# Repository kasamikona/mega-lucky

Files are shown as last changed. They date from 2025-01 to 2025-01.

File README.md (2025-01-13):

# Mega-Lucky
Ultimate IO mod for the Lucky Group electronic guitar toy (らっき組 ギター) RK-001, made by People Co., Ltd.  

The guitar toy in question has no external connectors. None at all, not even a headphone jack.
This project adds a 3.5mm line-out, a 6VDC barrel jack power input,
and MIDI in/out through additional 3.5mm TRS jacks.  

## Line out
The line-level audio output is amplified from the DAC output directly.
The DAC is stereo but the built-in volume pot is only mono, so I have chosen to bypass the pot for line-out.
In the future I may look into ways of including the pot without significant physical mods.
There are option jumpers to filter out the strong bass designed for the internal speaker.  

## Power
The power input intercepts the battery connector to allow external 6VDC as an alternative.
The safe range is actually 4.5 to 9 volts, but the built-in regulator will run hotter at higher voltages.
There is no overvoltage protection, but polarity protection and minimal filtering is included.  

## MIDI
The MIDI connections take advantage of some unlabeled test points on the guitar's PCB.
The guitar is based around a Yamaha XU947C0 LSI chip, which integrates a CPU and MIDI synth.
I found that its MIDI input and output pins (same pins as on a DB51XG) are fully functional.
Input may be used as a MIDI synth module combined with line-out, while output implements a basic MIDI guitar controller.
The Mega-Lucky board provides these MIDI in/out connections via type-A\* TRS connectors.  

## Installation
A proper visual installation guide will be made once the full functionality of the mod is verified.  

For now some rough steps:
- Desolder speaker wires, take the main board out.
- Remove two mixing resistors R10,R45 from the main board.
- Add two wires and optional shield to the DAC (IC3) output pins (L closest to pot).
- If reusing original battery connector, desolder it and install on mod board, otherwise use new connector.
- Use the 3D-printed drill guide to mark and drill holes (6.5-7mm for TRS, 8-9mm for DC).
- Solder the audio wires to the marked points on the mod board.
- Carefully wiggle the main board and mod connectors into place, mind the ribbon cables.
- Put M3 washers (0.5mm thick) between the boards at the screw holes and screw everything back in.
- Wire the MIDI pads to the relevant test points\*\*.
- Solder remaining 6 pads to the adjacent pads/pins.
- Resolder speaker wires or add some kind of connector.
- Solder the `HI-BASS` option jumper if desired. DO NOT set the `LOUD` jumpers on v1.0 boards.
- Solder MIDI type jumpers\* for your adapters.
- Extend the battery cable if necessary to reach the new location. Don't plug into old location.\*\*\*

\* MIDI TRS type:
Recommended type A (MIDI standard, KORG, Akai, Make Noise etc).
Alternative type B (Arturia, Novation etc).
You may need extra wire clippings to bridge the jumpers for type B on v1.0 boards.  

\*\* MIDI test points (will add photos later):
Below the big `DY798` text, the second test point down is MIDI out (to `M.TX`).
Further down are 2 more points, furthest to the right is MIDI in (to `M.RX`).  

\*\*\* Battery connector safety:
The original battery connector pads are not disconnected when external DC is used.
Using these may cause extensive damage if external DC is connected with batteries in place.
You must plug the battery cable into the new location on the mod board instead.  

## PCB assembly notes
- Clean out castellated pads with tweezers if produced the cheap way (i.e. not paying for special routing).
- Shave the top-front straight edge of the TRS connectors if new to ensure a proper fit.
- You may wish to leave some connector pins unsoldered to allow realigning during installation.
- Don't populate Q1-Q3, R25-R28, these are experimental alternative MIDI out driver.
- DO NOT set the `LOUD` jumpers on v1.0 boards, this is broken. Leave R19-R22 & C13 unpopulated.

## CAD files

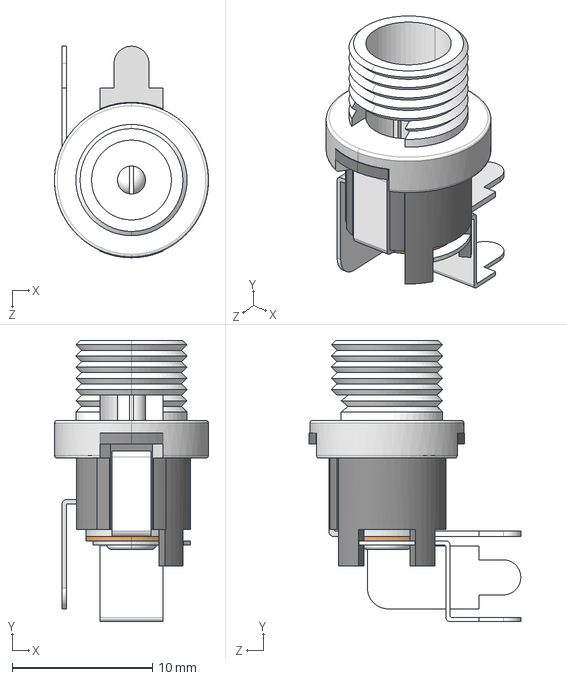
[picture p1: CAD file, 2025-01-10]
ConnectorMod/PJ-066A.step
11.0 x 20.1 x 15.1 mm

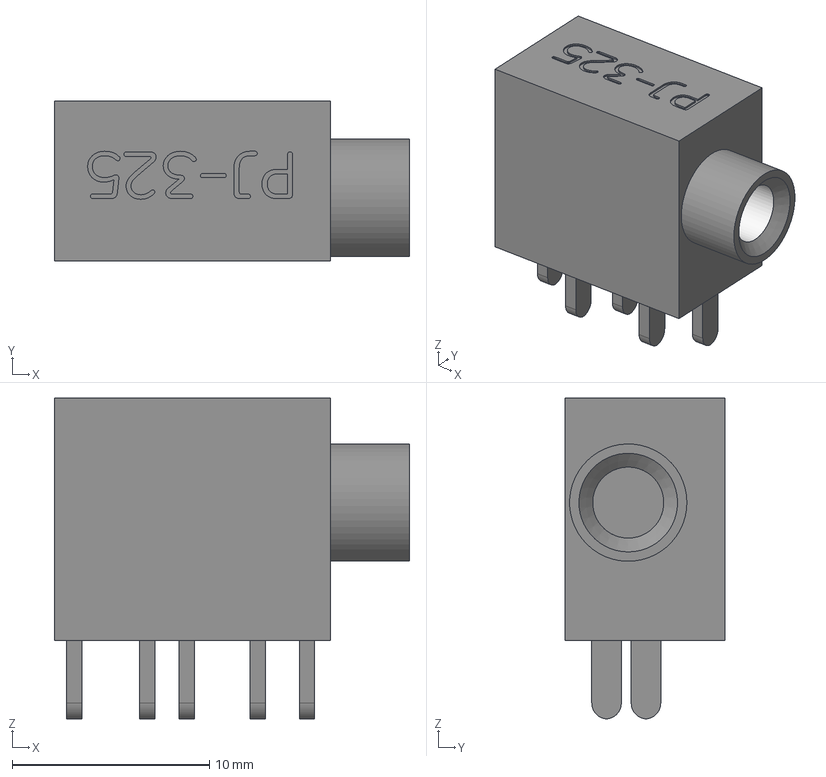
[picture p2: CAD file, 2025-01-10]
ConnectorMod/PJ-325.stp
18.0 x 8.10 x 16.3 mm

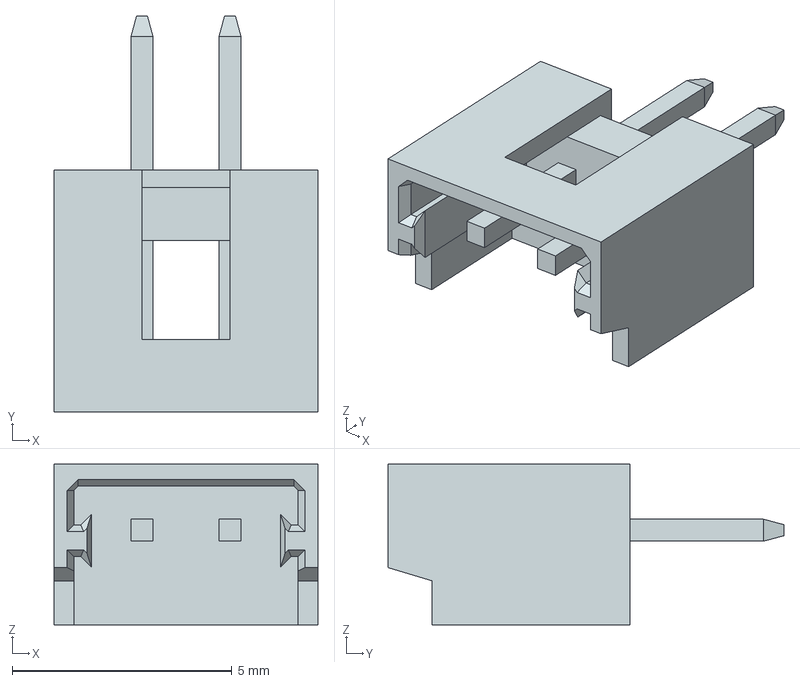
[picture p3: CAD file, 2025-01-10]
ConnectorMod/53253-0270.stp
6.00 x 9.00 x 3.65 mm

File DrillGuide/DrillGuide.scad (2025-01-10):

c1 = [-37,36.5];
c2 = [-16,149];
r1 = 60;
r2 = 62.5;
r3 = 125;

dirtyPreview=false;
renderShell=false;

boardoffset=4-0.5;
holeexp=0.;
holes = [
    [[21,21.0,6.5],15,8.0+holeexp],
    [[23,36.5,7.0], 0,6.5+holeexp],
    [[22,49.5,7.0], 0,6.5+holeexp],
    [[22,62.5,7.0], 0,6.5+holeexp],
];
shellheight=19;
shellTolerance=0.15;
pilotHole=true;

epsilon = 0.001;
cdetail = $preview?4:1;

module prerender(convexity=undef) {
    if(!dirtyPreview) {
        render(convexity) children();
    } else {
        children();
    }
}

function vlen(v) = sqrt(v.x*v.x+v.y*v.y);
function distAlongV(v,d) = v*d/vlen(v);
function cfn(r) = max(8,ceil(2*PI*r/cdetail));

function intersectTwoCircles(c1,r1,c2,r2) =
    let(x1=c1.x,y1=c1.y,x2=c2.x,y2=c2.y,
    centerdx = x1-x2, centerdy = y1-y2,
    R = sqrt(centerdx*centerdx + centerdy*centerdy),
    ttol=1e-4)
    (abs(r1-r2)<=R+ttol && r1+r2>=R-ttol) ? let(
        a = (r1*r1-r2*r2) / (2*R*R),
        r2r2 = (r1*r1-r2*r2),
        c = sqrt(max(0,2*(r1*r1+r2*r2)/(R*R)
            - (r2r2*r2r2)/(R*R*R*R) - 1)),
        fx = (x1+x2)/2 + a*(x2-x1),
        gx = c*(y2-y1)/2,
        ix1 = fx+gx,
        ix2 = fx-gx,
        fy = (y1+y2)/2 + a*(y2-y1),
        gy = c*(x1-x2)/2,
        iy1 = fy+gy,
        iy2 = fy-gy
    ) [[ix1, iy1], [ix2, iy2]] : [];

function intersectLineCircle(p1,p2,c,r) =
    let(cx=c.x,cy=c.y,p1c=p1-c,p2c=p2-c,
    x1=p1c.x,y1=p1c.y,x2=p2c.x,y2=p2c.y,
    dx=x2-x1,dy=y2-y1,dr=sqrt(dx*dx+dy*dy),
    D=x1*y2-x2*y1,
    k=r*r*dr*dr-D*D)
    (k>=0) ? let(
        dr2=dr*dr,
        kd=sqrt(k)/dr2,
        fx=D*dy/dr2+cx,
        gx=(dy<0?-1:1)*dx*kd,
        ix1=fx+gx,
        ix2=fx-gx,
        fy=(-1)*D*dx/dr2+cy,
        gy=abs(dy)*kd,
        iy1=fy+gy,
        iy2=fy-gy
    ) [[ix1, iy1], [ix2, iy2]] : [];

module outerCircles(h,off,sl) union() {
    r1a = r1-off;
    r2a = r2-off;
    r1b = r1a-h*sl;
    r2b = r2a-h*sl;
    translate(c1)
        cylinder(h=h,r1=r1b,r2=r1a,$fn=cfn(r1));
    //translate(c2)
    //    cylinder(h=h,r1=r2b,r2=r2a,$fn=cfn(r2));
}

c3 = intersectTwoCircles(c1,r1+r3,c2,r2+r3)[0];
module innerCircleFill(h,off,sl) {
    r3a = r3+off;
    r3b = r3a+h*sl;
    rs=max(0,-h*sl);
    ip1 = c1+distAlongV(c3-c1,r1-off+rs);
    ip2 = c2+distAlongV(c3-c2,r2-off+rs);
    
    prerender(convexity=10)
    difference() {
        linear_extrude(h)
        hull() {
            translate(c1) circle(r=epsilon);
            translate(ip1) circle(r=epsilon);
            translate(ip2) circle(r=epsilon);
            translate(c2) circle(r=epsilon);
        }
        translate([0,0,-epsilon])
        translate(c3) cylinder(h=h+2*epsilon,
            r1=r3b,r2=r3a,$fn=cfn(r3));
    }
}

module inclusionShape(h,xoff) {
    translate([0,0,-epsilon])
    linear_extrude(h+2*epsilon)
    polygon([
        [-xoff,xoff],[50,-50],[50,75],
        [-xoff,75+(50+xoff)/5]
    ]);
}

module endRoundProfile() {
    tol=shellTolerance;
    ww=3;
    xo=(4.5+ww)/2+tol;
    yo=0;
    ch1=shellheight+1-4.5;
    ch2=shellheight+1-2.0;
    union() {
        translate([-xo,yo,4.5])
            cylinder(h=ch1,d=ww,$fn=cfn(ww)*2);
        translate([xo,yo,2.0])
            cylinder(h=ch2,d=ww,$fn=cfn(ww)*2);
        translate([0,0,shellheight+1+3])
        rotate([90,0,0])
        linear_extrude(ww,center=true)
        polygon([
            [-xo-ww/2-1.5,0],
            [-xo-ww/2,-3],
            [xo+ww/2,-3],
            [xo+ww/2+1.5  ,0]
        ]);
    }
}

module endRounds() {
    ep1 = intersectLineCircle([0,0],[50,-50],
        c1,r1-2.25)[1];
    ea1 = 45;
    ep2 = intersectLineCircle([0,85],[50,75],
        c3,r3+2.25)[0];
    ea2 = atan(1/5);
    ch = shellheight+1;
    translate(ep1) rotate([0,0,-ea1])
        endRoundProfile();
    translate(ep2) rotate([0,0,-ea2])
        endRoundProfile();
}

module previewShell() {
    h=shellheight;
    color("#8AF")
    //prerender()
    difference() {
        intersection() {
            difference() {
                union() {
                    outerCircles(h,0,0.07);
                    innerCircleFill(h,0,0.07);
                }
                translate([0,0,3])
                union() {
                    outerCircles(h,4.5,0);
                    innerCircleFill(h,4.5,0);
                }
            }
            inclusionShape(h,0);
        }
        for(hole = holes) {
            hpos = hole[0];
            hangl = hole[1];
            hdiam = hole[2];
            translate([hpos[0],hpos[1],
                h-hpos[2]-boardoffset])
            rotate([0,90,-hangl])
            cylinder(h=10,d=hdiam,
                center=true,$fn=cfn(hdiam/2)*2);
        }
    }
}
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

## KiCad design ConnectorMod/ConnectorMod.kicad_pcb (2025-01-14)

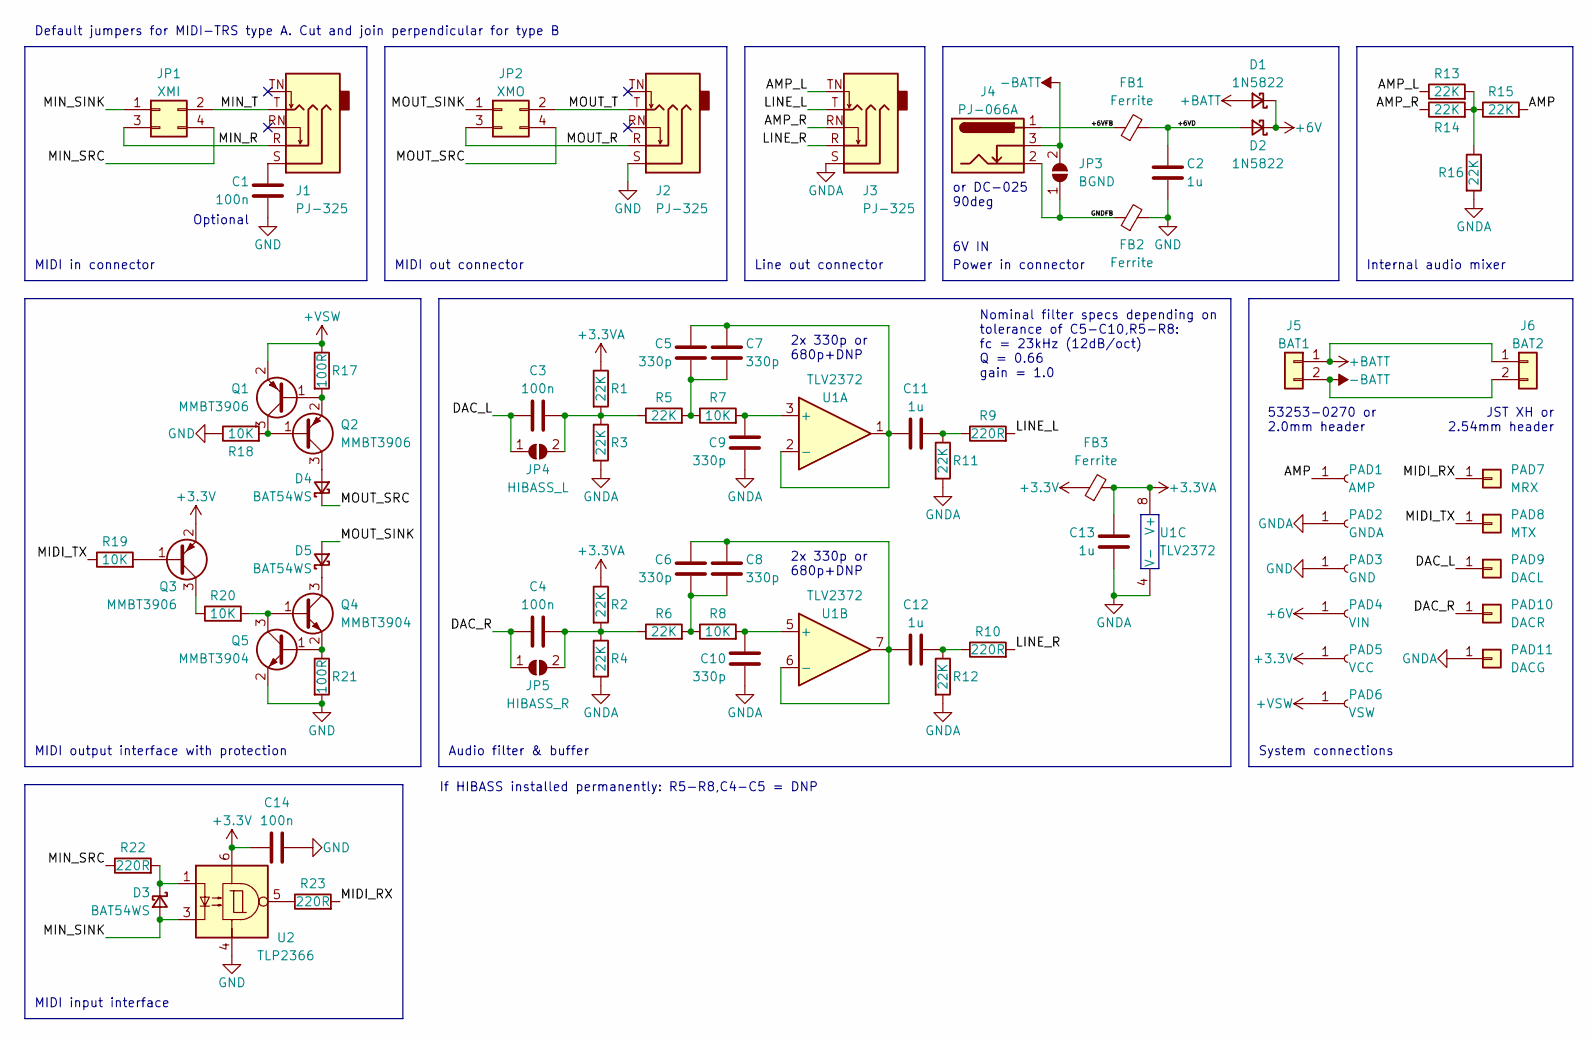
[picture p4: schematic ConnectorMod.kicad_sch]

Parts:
C1, C14: 100n; C_0603_1608Metric
C2, C11, C12, C13: 1u; C_0805_2012Metric
C3, C4: 100n; C_0805_2012Metric
C5, C6, C7, C8, C9, C10: 330p; C_0805_2012Metric
D1, D2: 1N5822; D_SMA
D3, D4, D5: BAT54WS; D_SOD-323
FB1, FB2, FB3: Ferrite; L_1206_3216Metric_Pad1.22x1.90mm_HandSolder
J1, J2, J3: PJ-325; PJ-325_Castellated-Edge
J4: PJ-066A
J5: BAT1; Molex_Micro-Latch_53253-0270_1x02_P2.00mm_Vertical
J6: BAT2; JST_XH_B2B-XH-A_1x02_P2.50mm_Vertical
JP1: XMI; SolderJumper_Cross
JP2: XMO; SolderJumper_Cross
JP3: BGND; SolderJumper_Custom
JP4: HIBASS_L; SolderJumper_Custom
JP5: HIBASS_R; SolderJumper_Custom
PAD1: AMP; Castellated-Pad_Custom
PAD2: GNDA; Castellated-Pad_Custom
PAD3: GND; Castellated-Pad_Custom
PAD4: VIN; Castellated-Pad_Custom
PAD5: VCC; Castellated-Pad_Custom
PAD6: VSW; Castellated-Pad_Custom
PAD7: MRX; TestPoint_Pad_D2.0mm
PAD8: MTX; TestPoint_Pad_D2.0mm
PAD9: DACL; TestPoint_THTPad_D2.5mm_Drill1.2mm
PAD10: DACR; TestPoint_THTPad_D2.5mm_Drill1.2mm
PAD11: DACG; TestPoint_THTPad_D2.5mm_Drill1.2mm
Q1, Q2, Q3: MMBT3906; SOT-23
Q4, Q5: MMBT3904; SOT-23
R1, R2, R3, R4, R5, R6, R11, R12, R13, R14, R15, R16: 22K; R_0603_1608Metric
R7, R8, R18, R19, R20: 10K; R_0603_1608Metric
R9, R10, R22, R23: 220R; R_0603_1608Metric
R17, R21: 100R; R_0603_1608Metric
U1: TLV2372; SO-8_3.9x4.9mm_P1.27mm
U2: TLP2366; SO-5_4.4x3.6mm_P1.27mm

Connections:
+3.3V: C14.1, FB3.1, PAD5.1, Q3.2 (E), U2.6
+3.3VA: C13.1, FB3.2, R1.1, R2.1, U1.8 (V+)
+6V: D1.1 (K), D2.1 (K), PAD4.1
+BATT: D1.2 (A), J5.1, J6.1
+VSW: PAD6.1, Q1.2 (E), R17.1
-BATT: J4.3, J5.2, J6.2, JP3.2 (B)
/+6VD: C2.1, D2.2 (A), FB1.2
/+6VFB: FB1.1, J4.1
/AMP: PAD1.1, R15.2
/AMP_L: J3.TN, R13.1
/AMP_R: J3.RN, R14.1
/DAC_L: C3.1, JP4.1 (A), PAD9.1
/DAC_R: C4.1, JP5.1 (A), PAD10.1
/GNDFB: FB2.1, J4.2, JP3.1 (A)
/LINE_L: J3.T, R9.2
/LINE_R: J3.R, R10.2
/MIDI_RX: PAD7.1, R23.2
/MIDI_TX: PAD8.1, R19.1
/MIN_R: J1.R, JP1.3
/MIN_SINK: D3.2 (A), JP1.1, U2.3
/MIN_SRC: JP1.4, R22.1
/MIN_T: J1.T, JP1.2
/MOUT_R: J2.R, JP2.3
/MOUT_SINK: D5.2 (A), JP2.1
/MOUT_SRC: D4.1 (K), JP2.4
/MOUT_T: J2.T, JP2.2
GND: C1.2, C2.2, C14.2, FB2.2, J2.S, PAD3.1, Q5.2 (E), R18.1, R21.2, U2.4
GNDA: C9.2, C10.2, C13.2, J3.S, PAD2.1, PAD11.1, R3.2, R4.2, R11.2, R12.2, R16.2, U1.4 (V-)
unnamed: C1.1, J1.S
unnamed: C5.2, C7.2, R5.2, R7.1
unnamed: C6.2, C8.2, R6.2, R8.1
unnamed: C11.2, R9.1, R11.1
unnamed: C12.2, R10.1, R12.1
unnamed: D3.1 (K), R22.2, U2.1
unnamed: D4.2 (A), Q2.3 (C)
unnamed: D5.1 (K), Q4.3 (C)
unnamed: C3.2, JP4.2 (B), R1.2, R3.1, R5.1
unnamed: C4.2, JP5.2 (B), R2.2, R4.1, R6.1
unnamed: Q1.1 (B), Q2.2 (E), R17.2
unnamed: Q1.3 (C), Q2.1 (B), R18.2
unnamed: Q3.1 (B), R19.2
unnamed: Q3.3 (C), R20.1
unnamed: Q4.1 (B), Q5.3 (C), R20.2
unnamed: Q4.2 (E), Q5.1 (B), R21.1
unnamed: R13.2, R14.2, R15.1, R16.1
unnamed: R23.1, U2.5
unnamed: C9.1, R7.2, U1.3 (+)
unnamed: C5.1, C7.1, C11.1, U1.1, U1.2 (-)
unnamed: C10.1, R8.2, U1.5 (+)
unnamed: C6.1, C8.1, C12.1, U1.6 (-), U1.7

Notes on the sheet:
2x 330p or 680p+DNP
Optional
Default jumpers for MIDI-TRS type A. Cut and join perpendicular for type B
Line out connector
JST XH or 2.54mm header
Audio filter & buffer
System connections
If HIBASS installed permanently: R5-R8,C4-C5 = DNP
Nominal filter specs depending on tolerance of C5-C10,R5-R8: fc = 23kHz (12dB/oct) Q = 0.66 gain = 1.0
or DC-025 90deg
Power in connector
53253-0270 or 2.0mm header
MIDI output interface with protection
MIDI input interface
MIDI in connector
MIDI out connector
6V IN
Internal audio mixer

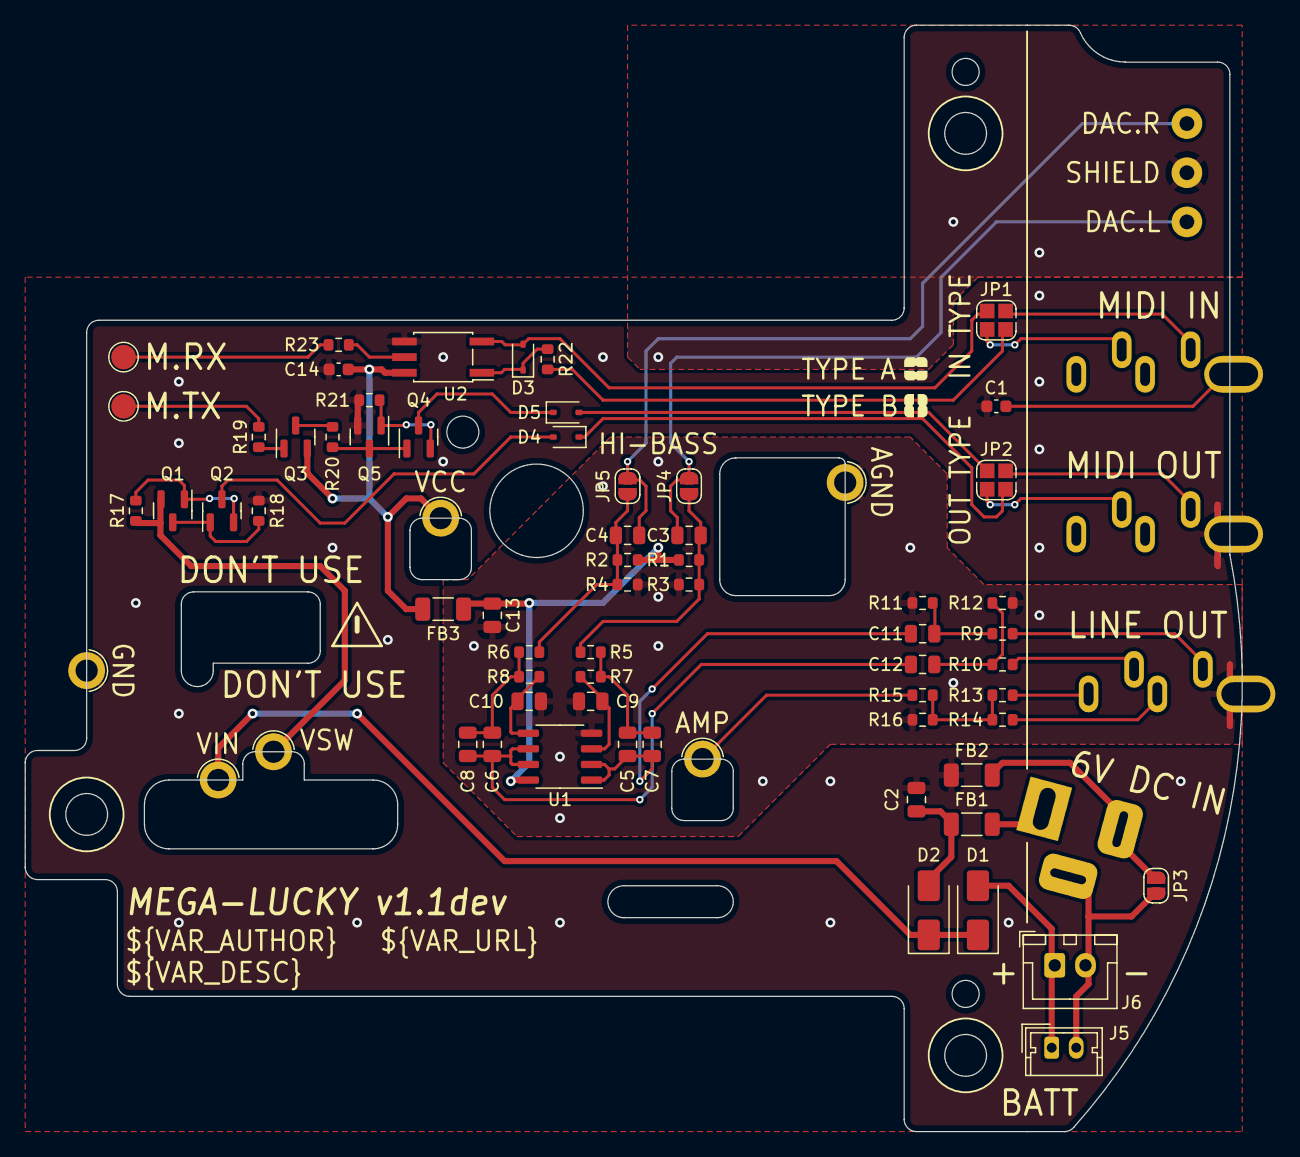
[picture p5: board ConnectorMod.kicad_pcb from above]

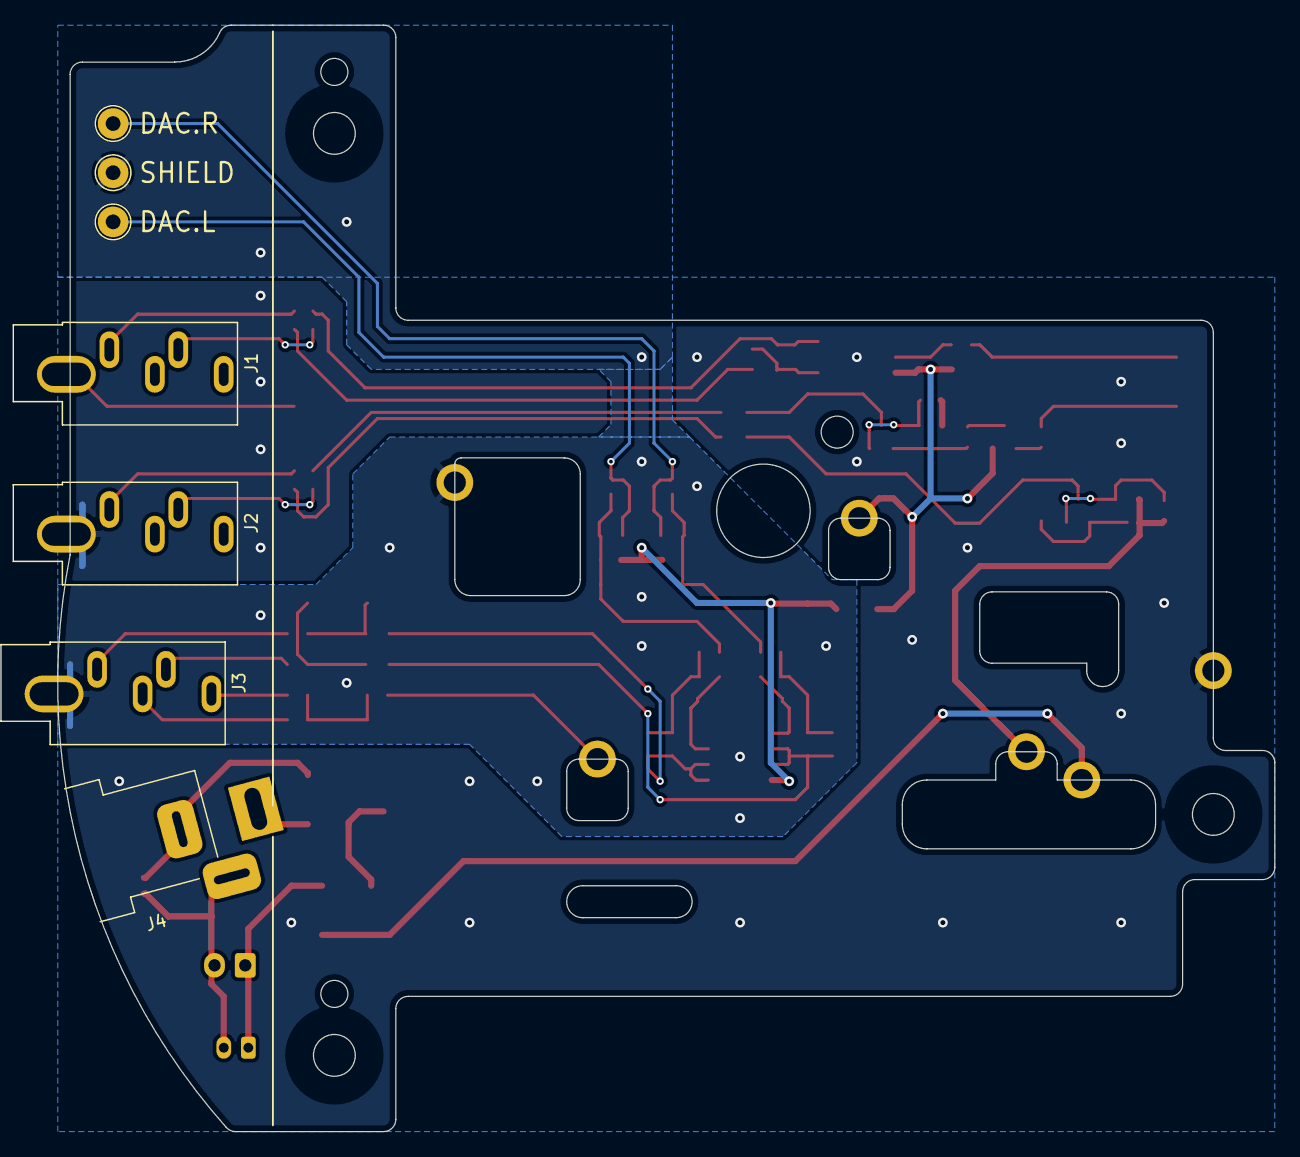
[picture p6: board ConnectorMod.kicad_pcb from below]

Board: 2 copper layers, 99.0 x 90.0 mm, 74 parts (7 on the bottom side), 50 nets.

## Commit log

2025-01-10 Publish v1.0 boards
    [53253-0270.stp, ConnectorMod.kicad_pcb, ConnectorMod.kicad_sch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]
2025-01-10 Add drill guide scad model
    [DrillGuide.scad]
2025-01-13 Remove loud jumper and tweak filter values
    [ConnectorMod.kicad_pcb, ConnectorMod.kicad_sch]
2025-01-13 Adjust outline and holes
    [ConnectorMod.kicad_pcb]
2025-01-13 Change MIDI type jumpers to cross pads
    [ConnectorMod.kicad_pcb, ConnectorMod.kicad_sch]
2025-01-14 Use protected source/sink for MIDI out
    [ConnectorMod.kicad_pcb, ConnectorMod.kicad_sch]
2025-01-14 Tidy up opamp circuit
    [ConnectorMod.kicad_pcb, ConnectorMod.kicad_sch]
2025-01-14 Make all audio caps at least 0805
    [ConnectorMod.kicad_pcb, ConnectorMod.kicad_sch]
